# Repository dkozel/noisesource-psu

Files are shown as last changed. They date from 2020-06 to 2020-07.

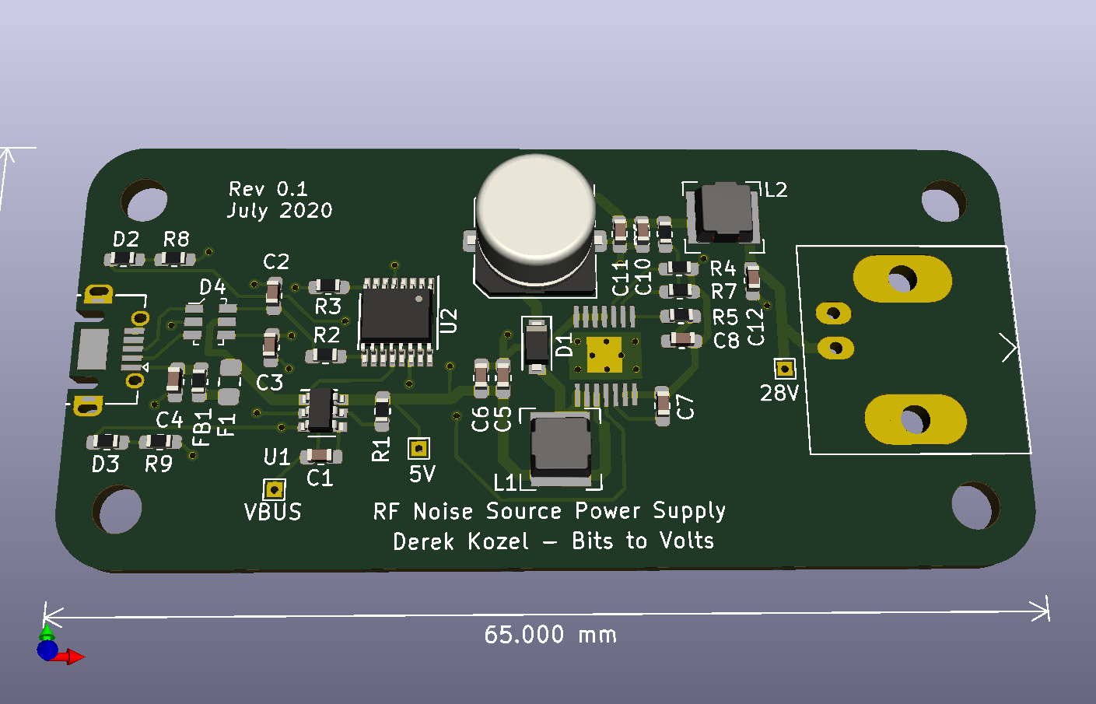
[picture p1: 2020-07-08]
pcb/noisesource-psu.png

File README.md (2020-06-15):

This is a computer controlled, portable power supply for RF Noise Sources such as the Keysight or Noisecom 346 series devices. It is powered by USB 2.0 and controlled without installing drivers from Linux, Windows, and OSX.

## Basic specs

Output:
* 28V +- 1V
* 100mA peak, 30-60mA average
* On/Off switching up to 1 Hz
* BNC female connector

Input:
* USB 2.0 compliant host
* 4.75 to 5.25 V
* 100 mA initial, 500 mA negotiated, 2.5 mA suspended
* USB 2.0 micro socket

Features:
* Output on/off control via USB command
* Optionally a switch to manually control output state
* LED showing output state
* LED showing input power good

## Software

The pyFTDI Python library allows the GPIO lines of an FT230X to be controlled from Linux, macOS, and Windows without the user installing any driver.

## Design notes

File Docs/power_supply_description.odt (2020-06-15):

This is a computer controlled, portable power supply for RF Noise Sources such as the Keysight or Noisecom 346 series devices. It is powered by USB 2.0 and controlled without installing drivers from Linux, Windows, and OSX.

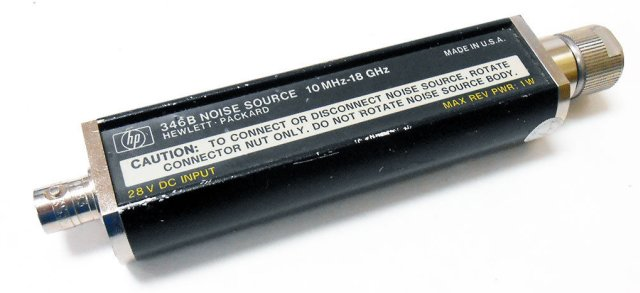
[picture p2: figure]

Figure 1: HP Noise Source

PCB Requirements

Output:

* 28V +- 1V

* 100mA peak, 30-60mA average

* On/Off switching up to 1 Hz

* BNC female connector

Input:

* USB 2.0 compliant host

* 4.75 to 5.25 V

* 100 mA initial, 500 mA negotiated, 2.5 mA suspended

* USB 2.0 micro socket

Features:

* Output on/off control via USB command

* Optionally a switch to manually control output state

* LED showing output state

* LED showing input power good

USB Interface Circuit

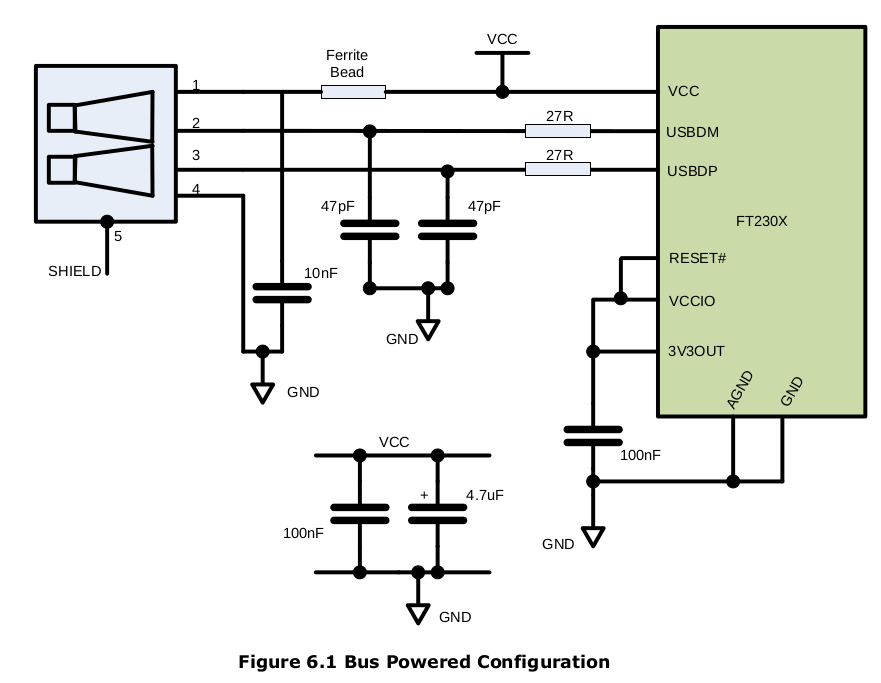
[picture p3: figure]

The FTDI FT230X provides a convenient way of properly requesting the full 500mA of USB power and providing easy GPIO access over USB without needing custom drivers on any major OS. It can additionally detect when the USB connection is to a dumb charger.

FTDI’s FT230X Datasheet page 22 shows the above schematic

CBUS pins can be used as status/control indicators of USB connection status or as GPIO from the host computer. They have a configurable drive strength of 4, 8, 12, or 16 mA.

BCD# indicates a dedicated charging port is connected (1A) [open drain]

PWREN# indicates a smart USB host is connected (500mA) [open drain]

SLEEP# indicates the USB host has slept/suspended the device (disable voltage output) [push-pull]

Software Configuration notes for Option bits in the MTP memory:

* Set Force Power Enable to enable PWREN# when a dumb charging port is connected.

* Set De-Activate Sleep to block the sleep signal when a dedicated charging port connection is detected.

TODO: Pull up resistors needed?

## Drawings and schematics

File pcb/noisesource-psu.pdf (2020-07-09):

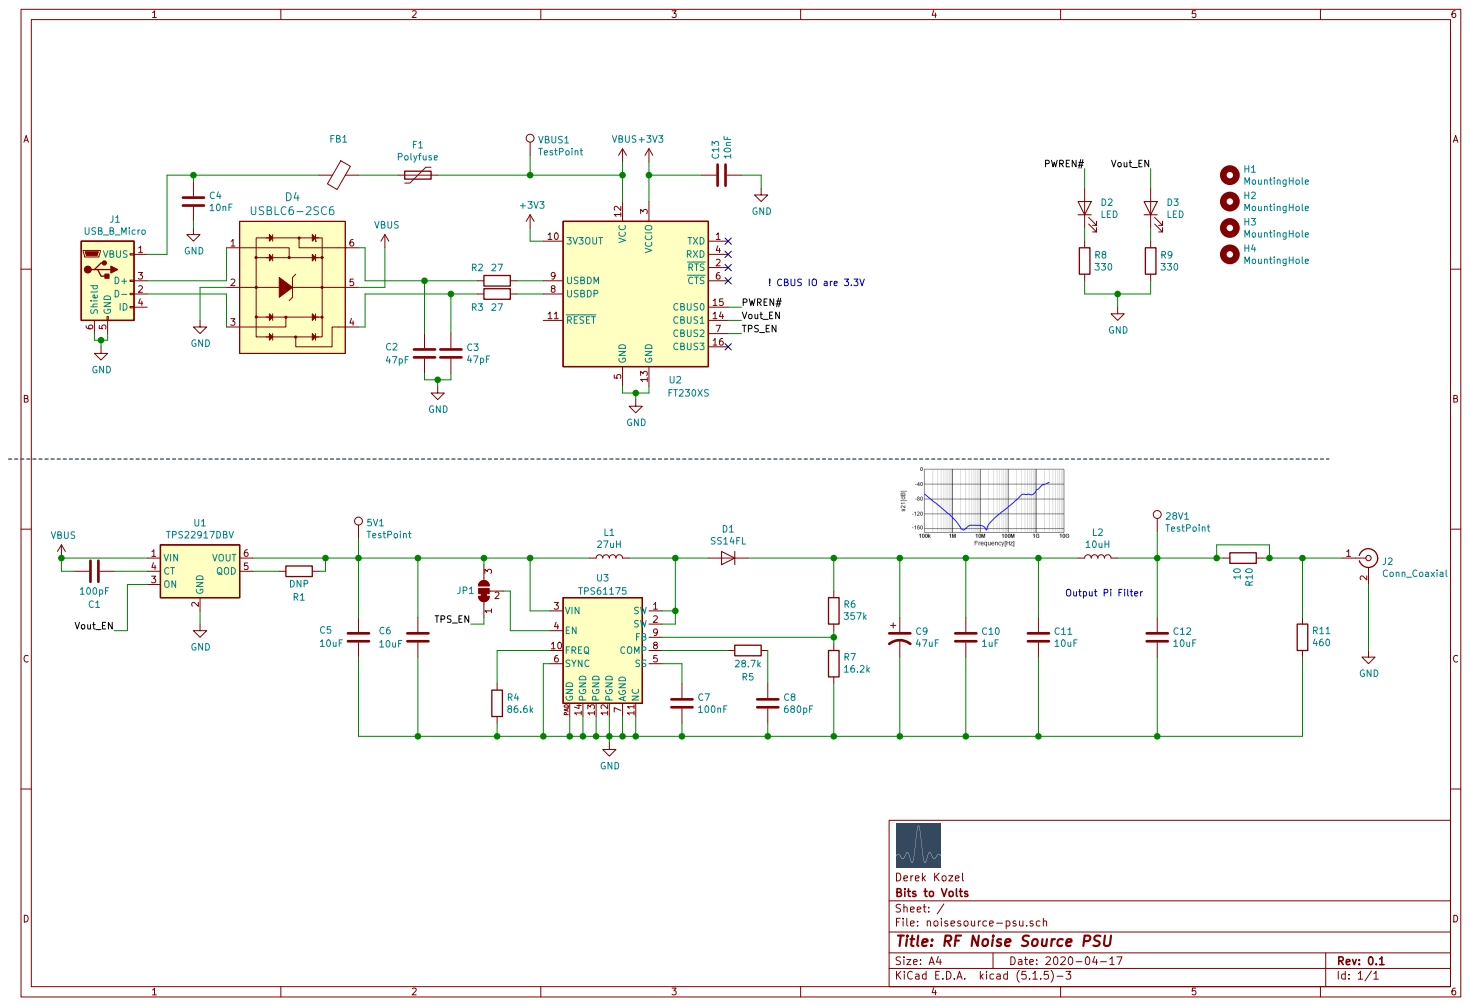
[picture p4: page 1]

PWREN# Output Pi Filter

2 ON 3 CT 4 QOD 5 VOUT 6 U1 TPS22917DBV R1 DNP

File: noisesource-psu.sch Sheet: / Bits to Volts Derek Kozel

Id: 1/1 Title: RF Noise Source PSU

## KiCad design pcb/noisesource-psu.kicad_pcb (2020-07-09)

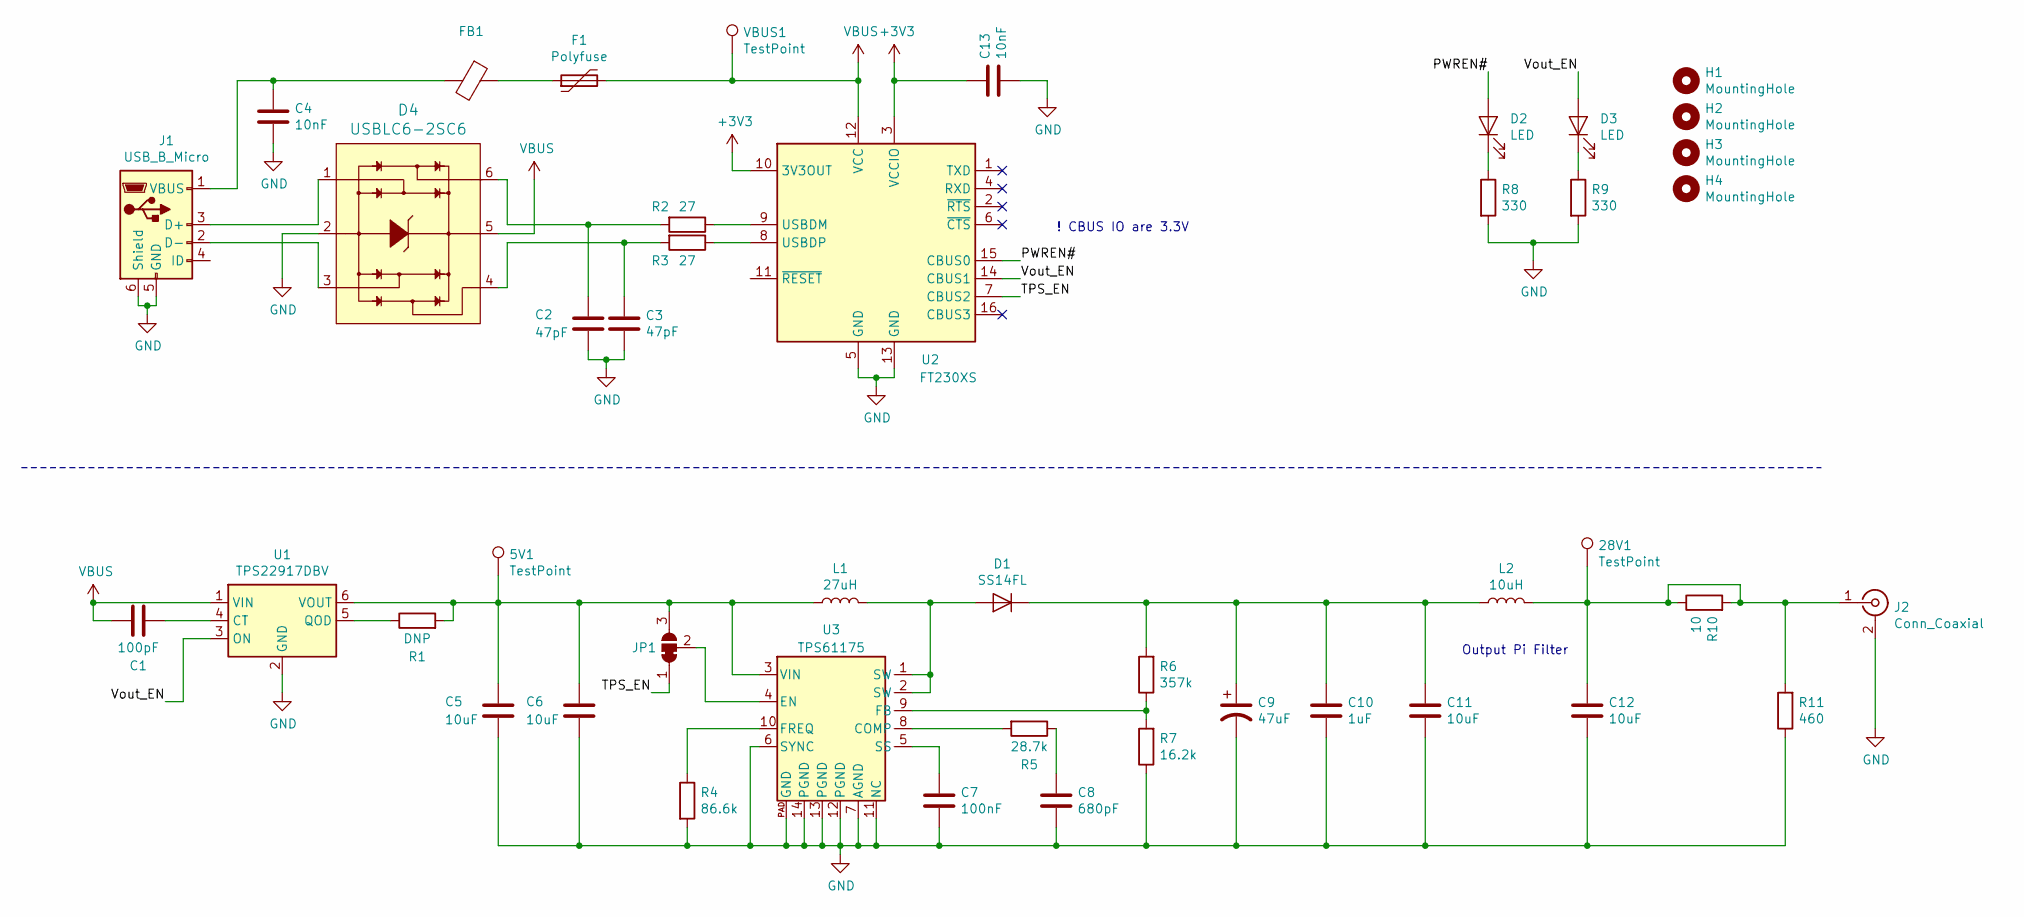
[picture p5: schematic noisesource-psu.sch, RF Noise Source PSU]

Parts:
5V1, 28V1: TestPoint; TestPoint_THTPad_1.0x1.0mm_Drill0.5mm
C1: 100pF; C_0603_1608Metric_Pad1.05x0.95mm_HandSolder; MPN 885012206003; Digi-Key PN 732-7922-1-ND
C2, C3: 47pF; C_0603_1608Metric_Pad1.05x0.95mm_HandSolder; MPN 885012006021; Digi-Key PN 732-7764-1-ND
C4, C13: 10nF; C_0603_1608Metric_Pad1.05x0.95mm_HandSolder; MPN 885012206040; Digi-Key PN 732-7959-1-ND
C5, C6, C11, C12: 10uF; C_0603_1608Metric_Pad1.05x0.95mm_HandSolder; MPN GRM188R6YA106MA73D; Digi-Key PN 490-13248-1-ND
C7: 100nF; C_0603_1608Metric_Pad1.05x0.95mm_HandSolder; MPN CL10B104KB8NFNC; Digi-Key PN 1276-1934-1-ND
C8: 680pF; C_0603_1608Metric_Pad1.05x0.95mm_HandSolder; MPN 885012206082; Digi-Key PN 732-8000-1-ND
C9: 47uF; C_Elec_8x6.2; MPN UUR1V470MCL6GS; Digi-Key PN 493-9586-1-ND
C10: 1uF; C_0603_1608Metric_Pad1.05x0.95mm_HandSolder; MPN UMK107BJ105KA-T; Digi-Key PN 587-2400-1-ND
D1: SS14FL; D_SOD-123F; MPN SS14FL; Digi-Key PN SS14FLCT-ND
D2, D3: LED; R_0603_1608Metric_Pad1.05x0.95mm_HandSolder; MPN 150060VS75000; Digi-Key PN 732-4980-1-ND
D4: USBLC6-2SC6; SOT23-6L; MPN USBLC6-2SC6; Digi-Key PN 497-5235-1-ND
F1: Polyfuse; Fuse_0805_2012Metric_Pad1.15x1.40mm_HandSolder; MPN 0805L110WR; Digi-Key PN F6725CT-ND
FB1: Ferrite_Bead; R_0603_1608Metric_Pad1.05x0.95mm_HandSolder; MPN BK1608HS220-T; Digi-Key PN 587-1869-1-ND
H1, H2, H3, H4: MountingHole; MountingHole_3.2mm_M3_Pad_Via
J1: USB_B_Micro; USB_Micro-AB_Molex_47590-0001; MPN 0475900001; Digi-Key PN WM17144CT-ND
J2: Conn_Coaxial; BNC_Amphenol_B6252HB-NPP3G-50_Horizontal; MPN B6252HB-NPP3G-50
JP1: SolderJumper_3_Bridged12; SolderJumper-3_P1.3mm_Bridged12_RoundedPad1.0x1.5mm
L1: 27uH; L_Bourns-SRN5040; MPN SRN5040-270M; Digi-Key PN SRN5040-270MCT-ND
L2: 10uH; L_Bourns-SRN5040; MPN SRN5040-100M; Digi-Key PN SRN5040-100MCT-ND
R1: DNP; R_0603_1608Metric_Pad1.05x0.95mm_HandSolder
R2, R3: 27; R_0603_1608Metric_Pad1.05x0.95mm_HandSolder; MPN RK73B1JTTD270J; Digi-Key PN 2019-RK73B1JTTD270JCT-ND
R4: 86.6k; R_0603_1608Metric_Pad1.05x0.95mm_HandSolder; MPN RK73H1JTTD8662F; Digi-Key PN 2019-RK73H1JTTD8662FCT-ND
R5: 28.7k; R_0603_1608Metric_Pad1.05x0.95mm_HandSolder; MPN RK73H1JTTD2872F; Digi-Key PN 2019-RK73H1JTTD2872FCT-ND
R6: 357k; R_0603_1608Metric_Pad1.05x0.95mm_HandSolder; MPN RK73H1JTTD3573F; Digi-Key PN 2019-RK73H1JTTD3573FCT-ND
R7: 16.2k; R_0603_1608Metric_Pad1.05x0.95mm_HandSolder; MPN RK73H1JTTD1622F; Digi-Key PN 2019-RK73H1JTTD1622FCT-ND
R8, R9: 330; R_0603_1608Metric_Pad1.05x0.95mm_HandSolder; MPN RK73B1JTTD331J; Digi-Key PN 2019-RK73B1JTTD331JCT-ND
R10: 10; R_0402_1005Metric; MPN 3502470RJT; Digi-Key PN A143324CT-ND
R11: 460; R_2010_5025Metric_Pad1.52x2.65mm_HandSolder; MPN 3502470RJT; Digi-Key PN A143324CT-ND
U1: TPS22917DBV; SOT-23-6; MPN TPS22917DBVR; Digi-Key PN 296-50498-1-ND
U2: FT230XS; SSOP-16_3.9x4.9mm_P0.635mm; MPN FT230XS-R; Digi-Key PN 768-1135-1-ND
U3: TPS61175; TSSOP14; MPN TPS61175PWPR; Digi-Key PN 296-24013-1-ND
VBUS1: TestPoint; TestPoint_THTPad_1.0x1.0mm_Drill0.5mm

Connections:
+3V3: C13.1, U2.3 (VCCIO), U2.10 (3V3OUT)
/PWREN#: D2.2 (A), U2.15 (CBUS0)
/TPS_EN: JP1.1 (A), U2.7 (CBUS2)
/Vout_EN: D3.2 (A), U1.3 (ON), U2.14 (CBUS1)
GND: C2.2, C3.2, C4.2, C5.1, C6.2, C7.2, C8.2, C9.2, C10.2, C11.2, C12.2, C13.2, D4.2, H1.1, H2.1, H3.1, H4.1, J1.5 (GND), J1.6 (Shield), J2.2 (Ext), R4.2, R7.1, R8.2, R9.2, R11.1, U1.2 (GND), U2.5 (GND), U2.13 (GND), U3.6 (SYNC), U3.7 (AGND), U3.11 (NC), U3.12 (PGND), U3.13 (PGND), U3.14 (PGND), U3.PAD (GND)
unnamed: 5V1.1, C5.2, C6.1, JP1.3 (B), L1.1, R1.2, U1.6 (VOUT), U3.3 (VIN)
unnamed: 28V1.1, C12.1, J2.1 (In), L2.2, R10.1, R10.2, R11.2
unnamed: C1.1, U1.4 (CT)
unnamed: C2.1, D4.6, R2.2
unnamed: C3.1, D4.4, R3.2
unnamed: C4.1, FB1.2, J1.1 (VBUS)
unnamed: C7.1, U3.5 (SS)
unnamed: C8.1, R5.1
unnamed: C9.1, C10.1, C11.1, D1.1 (K), L2.1, R6.2
unnamed: D1.2 (A), L1.2, U3.1 (SW), U3.2 (SW)
unnamed: D2.1 (K), R8.1
unnamed: D3.1 (K), R9.1
unnamed: D4.1, J1.3 (D+)
unnamed: D4.3, J1.2 (D-)
unnamed: F1.1, FB1.1
unnamed: JP1.2 (C), U3.4 (EN)
unnamed: R1.1, U1.5 (QOD)
unnamed: R2.1, U2.9 (USBDM)
unnamed: R3.1, U2.8 (USBDP)
unnamed: R4.1, U3.10 (FREQ)
unnamed: R5.2, U3.8 (COMP)
unnamed: R6.1, R7.2, U3.9 (FB)
VBUS: C1.2, D4.5, F1.2, U1.1 (VIN), U2.12 (VCC), VBUS1.1

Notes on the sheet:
! CBUS IO are 3.3V
Output Pi Filter

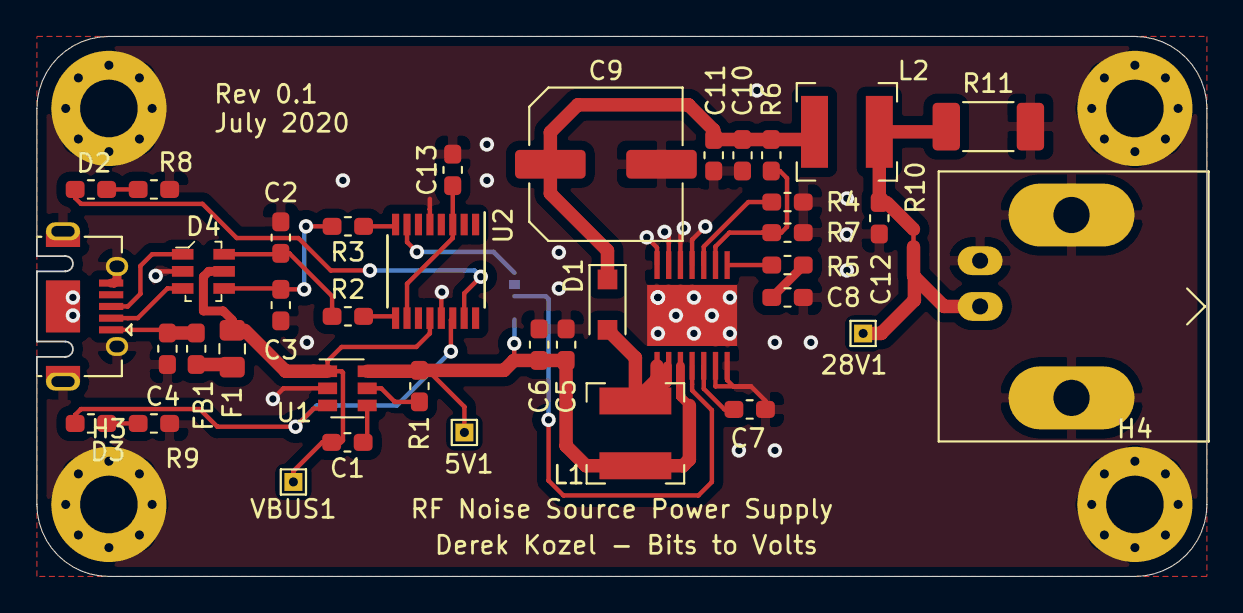
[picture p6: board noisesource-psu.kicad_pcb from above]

Board: 2 copper layers, 65.0 x 30.0 mm, 45 parts (1 on the bottom side), 28 nets.

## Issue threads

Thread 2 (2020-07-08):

Two copies of U2/U4 in the schematic

sconklin, 2020-07-08:
I'm using kicad version 5.0.2-bee76a0~ubuntu18.04.1, and it complained that the symbol for the FT230XS was out of date. I updated it, and ended up with two stacked parts in the same location, U2 and U4. I can't tell whether this is from the updated library or an error in the schematic.

U4 doesn't appear on the PCB.

dkozel, 2020-07-08:
The use of libraries in KiCad has been one of the larger learning points. I'll double check the schematic on my side. I'm using Kicad 5.1.5 and git HEADs of the standard libraries.

sconklin, 2020-07-08:
I think that KiCAD may use the word "older" in places where the library is newer. I need to review my library defaults as well.

dkozel, 2020-07-09:
There was indeed a second FT230XS in the schematic. I had only used one in the layout so a quick fix.

Thanks!

Closed 2020-07-09.

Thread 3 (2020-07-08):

Jumper choice

sconklin, 2020-07-08:
This is a matter of opinion, but I'd use a single  SolderJumper_3 type instead of the two jumpers you have for TPS_EN. It makes it harder to misconfigure the jumpers and short the CBUS2 output to 5V1.

dkozel, 2020-07-08:
Ah! Yes. That makes a lot of sense. I ended up with the two separate jumpers because the idea to have them came up fairly late and I originally had each part of the jumper next to each IC. I was also imagining the use of a 0 Ohm resistor to do the bridging, but that's overkill for a small prototype run.

daveb377, 2020-07-09:
0 ohm resistors are pretty cheap

dkozel, 2020-07-09:
Resolved by moving to a single three pad jumper and footprint.

Closed 2020-07-09.

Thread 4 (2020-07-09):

Output Rise time

daveb377, 2020-07-09:
Is there a specification for Rise time/Fall time on the +28V for a Noise diode? The +28V supply comes up as the TPS61175 comes up, and there's ~ 70uF of capacitance to charge there. If you're going to automate a Y-Factor measurement like the HP8970, you'll be strobing the noise source on/off to get Thot/Tcold measurements, so slow rise time/fall time will effect the measurements. Something to look at.

dkozel, 2020-07-09:
My plan is to automate the noise figure measurements using GNU Radio and general purpose SDRs. I'm assuming that the maximum switching rate will be ~5 Hz with a 50% duty cycle. I haven't been able to find any spec for the rise/fall time for a noise diode.

I'm most concerned about ensuring that no more than 500mA is drawn from the USB 5V source which limits us to ~90mA at 100% efficiency, or more reasonably about 75 mA at 85% efficiency. I'm hoping that the relatively high input capacitance and two layers of soft start will give me enough room to tune the rise time vs inrush current.

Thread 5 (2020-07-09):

Layout Comments

daveb377, 2020-07-09:
- The LED's are awfully close to the mounting holes. If the screwdriver slips, you might damage the LED's.
- the top side needs a ground pour.
- The R6/R7 voltage divider components need to be closer together. Shift R4 left, towards C9 and you can move R6/R7 closer.
- If you rotate C9 180 degrees, the +28V line can be shortened up. tradeoff is the ground there gets a little worse, but adding a ground plane would mitigate this
- The 28V1 test point is very close to the connector, it's going to be hard to probe.
- LED on +28V line would be useful. 3 mA@28V isn't much power, and would be good to have.

dkozel, 2020-07-10:
- [x] Added top ground pour
- [x] 28V testpoint moved away from the connector

I think reworking the entire path of the 28V line is worth doing and I'll take a shot at it for the r0.2. I think I improved it a little in this rev.

I'm going to remove the mounting holes in the second revision, so not worrying about that for now. Thanks for pointing it out though. I didn't want to add a 28V LED since the Vout Enable LED should be acting to signal that the output is on, hopefully it serves the purpose. Once the mounting holes are removed, there should be lots of space to move the LEDs to be next to the BNC connector.

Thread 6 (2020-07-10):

Revision 0.2 Design Notes

dkozel, 2020-07-10:
- [ ] Resize the PCB to 39x60mm to fit Hammond 1455D602BK enclosure
- [ ] Add 4mm keepouts on long edges to clear the case
- [ ] Change BNC connector to Molex 0731000105 (shorter and cheaper)
- [ ] Rework 28V track to shorten it
- [ ] Move LEDs to next to the BNC

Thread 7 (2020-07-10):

Enclosure Design

dkozel, 2020-07-10:
The Hammond 1455D602BK enclosure is affordable and a good form factor for this. Small enough to be portable and proportionate to a noise source, but large enough to not wildly get pulled around by a cable.

The PCB outline is 39x60mm. 4mm of clearence is needed on either side of the long edges.

The top and bottom have very slightly recessed panels that would fit a 54x32.5mm sticker or design.

The front and rear panels are 1mm thick aluminum. The black coating is resiliant but can be laser etched. Since both faceplates will need cutouts there's also the option of engraving text on them.

marcusmueller, 2020-07-11:
1455D602BK:

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

Love it. One can glue two magnets on any of the sides, and affix them to any desktop-device steel enclosure that one has standing around anywhere, too.

How are you going to make use of the LEDs, though? COTS LED->Front panel light guides (like on say, the B2x0) need cutouts around the LED for affixing; maybe add a second, unpopulated 2-pin through-hole in parallel to the existing LEDs so that you can solder & bend "classical" 3–5mm diameter leaded LEDs?

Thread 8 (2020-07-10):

3D models

dkozel, 2020-07-10:
Currently the USB connector, BNC connector, and several ICs do not have 3D models in KiCad, but manufacturers have supplied STEP files for them. They need to be converted to VRML and upstreamed. Most important are the connectors for physical fit.

- [ ] https://www.molex.com/molex/products/part-detail/rf_coax_connectors/0731000105
- [ ] https://www.molex.com/molex/products/part-detail/io_connectors/0475900001
- [ ] FTDI FT230XS

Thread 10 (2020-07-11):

Validate Voltage Ratings

marcusmueller, 2020-07-11:
Love the output filter! I don't see any reasonable argument for it ever resonating, but, still, 28+1 V is ever so slightly too close to the 35 V of your 10 µF MLCCs,  C11 and C12, for my overly anxious mind.

dkozel, 2020-07-11:
Agreed. I'm going to review the BOM for the next rev, looking to cost save and improve safety margins/ratings where possible.

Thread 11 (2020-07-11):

Idea: use CBUS3 as software-readable "output good" indicator

marcusmueller, 2020-07-11:
... using a voltage divider on the output. Might even incorporate that into the 460 Ω load resistor.

dkozel, 2020-07-11:
The load resistor is going away in the next rev, its for ease of bringup although realistically I probably should have just pushed a 460 Ohm through hole into the BNC. :)

But yes, there's probably an easy way of adding a divider and having a software readable power good on the final 28V with at least some basic level of functionality.

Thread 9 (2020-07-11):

Don't break bottom ground plane if avoidable

marcusmueller, 2020-07-11:
Would've done this as a quick PR, but alas, my KiCAD's too new, doesn't allow me to save as your file format :(

So, here's what I'd change:

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

Looking at this, the via between C13 and the FTDI IC is probably superfluous / ill-advised; I should've moved C13 closer to the IC.

The 12 Mb/s USB data lines aren't *very* fast, so I presume that the coupling when routing them below the other line (R3) isn't that bad.

dkozel, 2020-07-11:
Ah! I like the sneak under the resistor. I'm assuming that the USB 1.1 traffic is going to be really resiliant to small routing faux paux like this.

Also yes, the other routing changes look good as well. I did pay attention to the splits in the ground plane and avoided them in the power converter section. That doesn't mean they shouldn't still be avoided where pragmatic.

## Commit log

2020-04-14 Initial project creation
    [noisesource-psu.kicad_pcb, noisesource-psu.sch]
2020-04-14 pcb: Continued initial schematic creation
    [noisesource-psu.sch]
2020-04-17 pcb: Added TPS61175 symbol to project library
2020-04-17 pcb: Changed voltage regulator to TPS61175
    The previous TLV61046 is not rated to handle the peak inductor
    currents during startup.
    [noisesource-psu.kicad_pcb, noisesource-psu.sch]
2020-06-15 Updated schematic
    Added PDF export
    Added comments on output filter and output switch
    [noisesource-psu.sch]
2020-07-07 schematic: Added output filter, added footprints
    [noisesource-psu.kicad_pcb, noisesource-psu.sch]
2020-07-08 pcb: Updated schematic and layout
    Schematic:
    Added testpoints
    Added ground pad to TPS51175
    Layout:
    Completed initial layout of PCB
    [noisesource-psu.kicad_pcb, noisesource-psu.sch]
2020-07-09 pcb: Updated schematic and layout
    Added 3.3v decoupling cap
    Added top ground fill
    Changed solder jumper footprint
    Added sense and test load resistors
    Changed SMPS ground pad to thermal fill
    Changed mounting holes to plated through vias with pads
    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
    [noisesource-psu.kicad_pcb, noisesource-psu.sch]
